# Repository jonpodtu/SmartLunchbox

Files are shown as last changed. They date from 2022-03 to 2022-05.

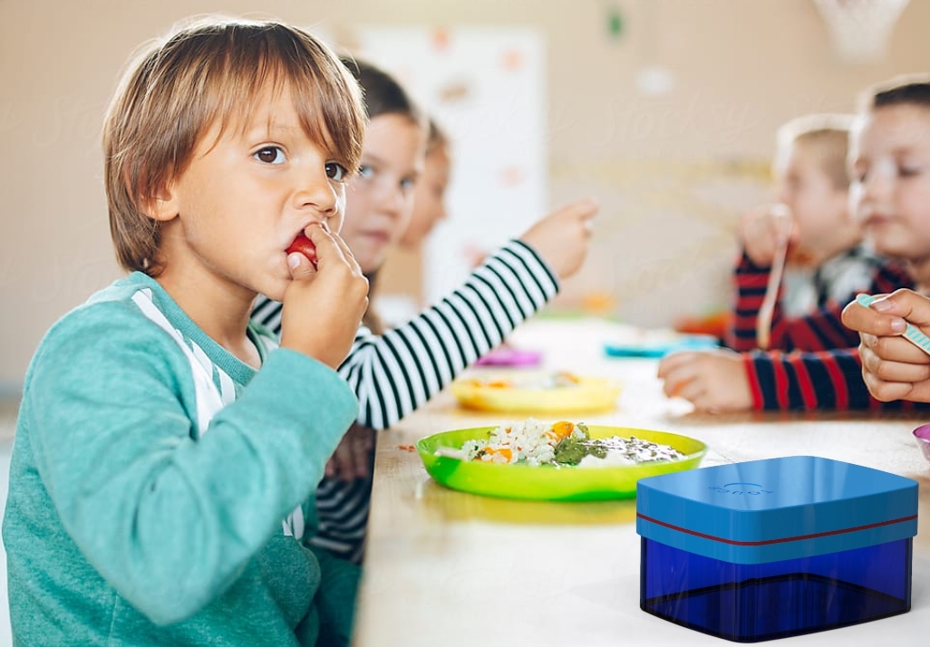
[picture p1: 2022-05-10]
renderings/Front page report.jpg

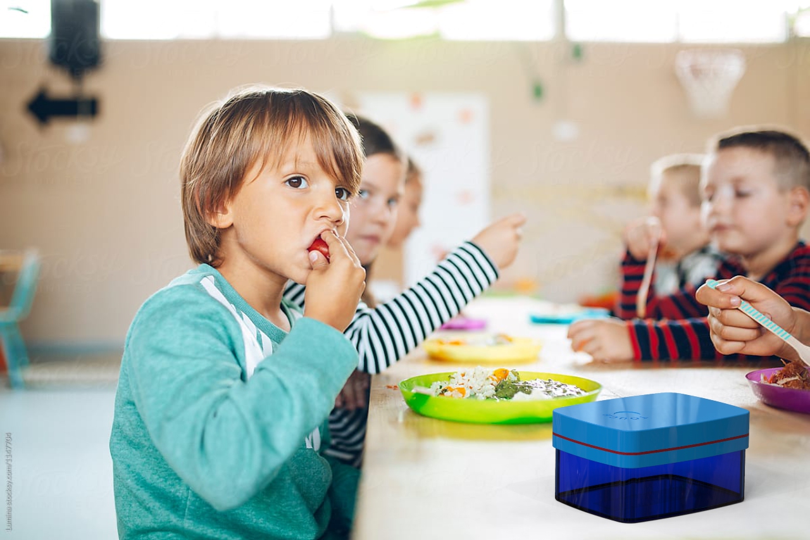
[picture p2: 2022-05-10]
renderings/Front page.jpg

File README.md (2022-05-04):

# SmartLunchbox
Repository for the SmartLunchbox project developed in course 34315

# Note to self
## GPIO Pins
Using the ESP32, we have the following connection for each of the different modules. All module use 5V. 

__MAX7219 LED Dot Matrix Module__
CLK: 2
SCL: 0
DIN: 4

__Photoresistor__
Analog Signal: 27

__DS18B20 Temperature Sensor__
Digital Signal: 26

__TTP223 Touch Sensor Module__
I/O: 15

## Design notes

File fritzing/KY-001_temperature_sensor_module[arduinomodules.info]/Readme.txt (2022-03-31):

//
// ARDUINOMODULES.INFO
// KY-001 Temperature sensor module
//
// https://arduinomodules.info/ky-001-temperature-sensor-module/
//

File includes:
 |
 |- KY-001 Temperature Sensor Module.fzpz	//Fritzing Custom Part
 |
 |- Readme.txt					//This file 

Changelog:
  
  Oct-2020
    -Fix PCB holes.
    -Fix PCB size.
    -Fix copper layers order on PCB.

Disclaimer:

KY-001 Temperature sensor module Fritzing Part is created by arduinomodules.info and published under Creative Commons Attribution-ShareAlike 4.0 International license (https://creativecommons.org/licenses/by-sa/4.0/).
You can use it, share it and/or modify it for any purposes as long as you distribute it under the same license and provide appropriate credit.

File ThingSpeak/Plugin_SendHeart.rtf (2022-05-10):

Title: Send Heart to Child (Plugin)
HTML Code:
<!-- This blog was used to create this functionality https://bennthomsen.wordpress.com/iot/iot-things/ti-cc3200-launchpad/sending-commands-to-device/ -->
<!DOCTYPE html>
<html style="height: 100%;">
<head>
<script type="text/javascript" src="//ajax.googleapis.com/ajax/libs/jquery/1.9.1/jquery.min.js"></script>

<style type="text/css">
body { background-color: white; }
</style>

<script type="text/javascript">
function heartOn(){
$.post('https://api.thingspeak.com/talkbacks/45773/commands.json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');
}
</script>

</head>
<body>
Click here to send a heart to let your kid know, you are thinking of them
</body>
<body>
<button onclick="heartOn()">Send Heart</button>
</body>
</html>
CSS Code
<style type="text/css">
body { background-color: #ddd; }
</style>
JavaScript Code
<script type="text/javascript">
document.write('<div>javascript active</div>');
</script>

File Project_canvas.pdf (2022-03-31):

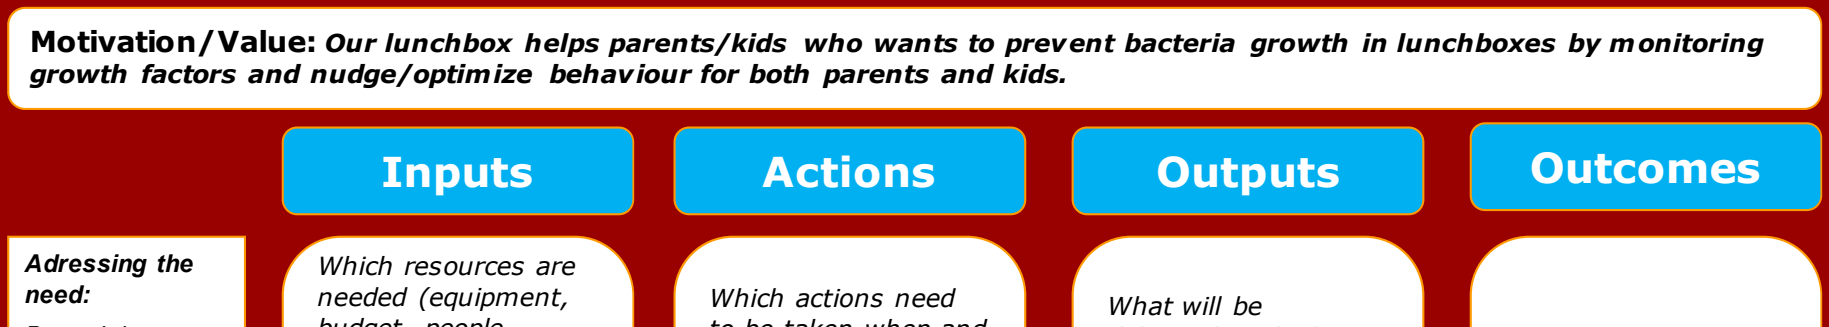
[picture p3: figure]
Adressing the need:; Inputs; Actions; Outputs; Outcomes; Which resources are needed (equipment,; Which actions need; What will be
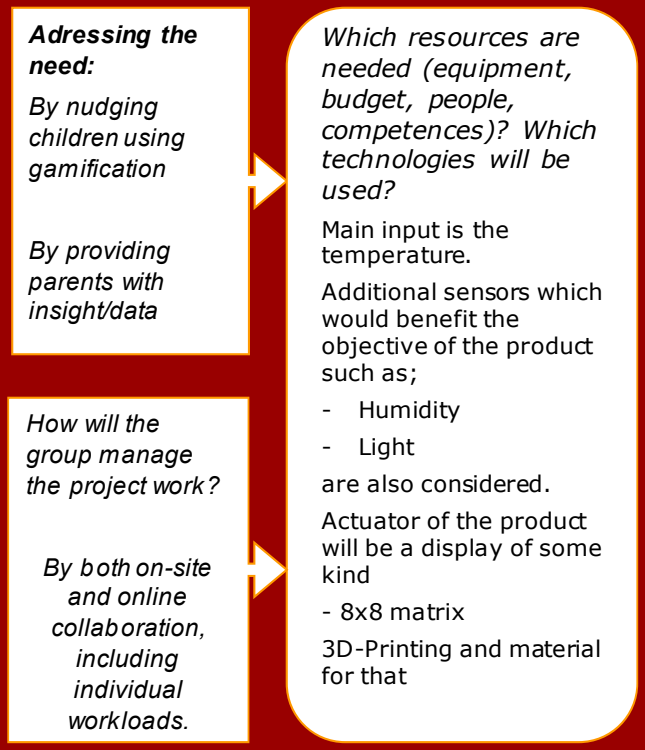
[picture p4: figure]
By nudging children using gamification; By providing parents with insight/data; budget, people, competences)? Which technologies will be used? Main input is the temperature. Additional sensors which would benefit the objective of the product such as; - Humidity - Light are also considered. Actuator of the product will be a display of some kind - 8x8 matrix 3D-Printing and material for that; How will the group manage the project work?; By both on-site and online collaboration, including individual workloads.

srru

IoT Project Planning | Project name: The Smart Lunch Box Group members: Jørgen, Simon, Jonas and Christian

Motivation/Value: Our lunchbox helps parents/kids who wants to prevent bacteria growth in lunchboxes by monitoring growth factors and nudge/optim ize behav iour for both parents and kids.

to be taken when and
by whom?
General structure: Both
online and physical
groupwork depending on
task of the day.
We try to challenge
ourselves by working
with what we are not
typically working with,
and then utilize that we
can aid each other within
different field.
Main responsibilities:
Jørgen: CAD
Simon: Thingspeak and
communication
Christian: C++
Programming
Jonas: Electronics

delivered and when?

### 21. April: 1. Iteration of

complete product.
This will include a 3D
printed lid for the lunchbox which can contain
the electronic
components. It will also
include final electronic
circuit with code that
works. Lastly it will
communicate with
Thingspeak service.

### 28. April: Final product

Polished product where
problems from last
delivery will be fixed.

### 4. May: Handin rapport

and presentation.

The project will help
school children avoid
bacteria corrupted
lunch boxes.

It will help parent
monitor and teach
children good food
safety practice.

If the project can
succesfully nudge
these behaviours, it
is a succes.

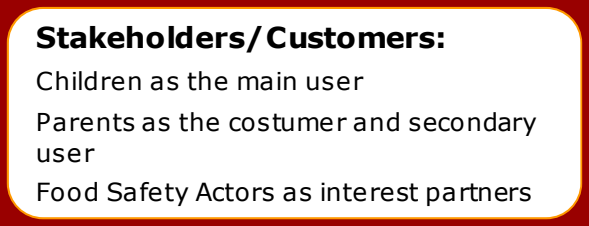
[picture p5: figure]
Stakeholders/Customers:; Children as the main user Parents as the costumer and secondary user Food Safety Actors as interest partners

### Assumptions: Assuming the environment of a brought-to-school lunch and the

possibility of storing this in a fridge.

Risks: What are the risks of the project? We will think about how the product should be designed to make it suitable for the environment. (Washable ie. Water resistant, placement of device etc.)

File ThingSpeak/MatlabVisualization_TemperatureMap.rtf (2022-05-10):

Title: Temperature Zone Map
Matlab Code:
% To create this plot, the following template from Thingspeak was used:
%Template MATLAB code for visualizing data from a channel as a 2D line
% TODO - Replace the [] with channel ID to read data from:
readChannelID = 1671827;
% TODO - Replace the [] with the Field ID to read data from:
fieldID1 = 1;

% Channel Read API Key
% If your channel is private, then enter the read API
% Key between the '' below:
readAPIKey = 'BSZB7OSERJ3O70S9';

%% Read Data %%

[data, time] = thingSpeakRead(readChannelID, 'Field', fieldID1, 'Numdays', 1, 'ReadKey', readAPIKey);

%Using plot first, to set a default window.
plot(time, data);
hold on

%Filling of diff. background zones
x = [0 100 100 0];
y = [5 5 8 8];
tz3 = fill(x,y,'green', 'LineStyle', 'none');
tz3.FaceAlpha = 0.5;
x = [0 100 100 0];
y = [0 0 5 5];
tz1 = fill(x,y,'green', 'LineStyle', 'none');
tz1.FaceAlpha = 0.8;
x = [0 100 100 0];
y = [8 8 40 40];
tz2 = fill(x,y,'red', 'LineStyle', 'none');
tz2.FaceAlpha = 0.5;
x = [0 100 100 0];
y = [40 40 120 120];
tz4 = fill(x,y,'red', 'LineStyle', 'none');
tz4.FaceAlpha = 0.8;

%Setting the window frame
xlim([min(time) max(time)])
ylim([0 max(data)+5])

%%Redraw the graph
plot(time, data, 'color', 'b', 'LineWidth', 1);
legend({'Temperature'})
hold off

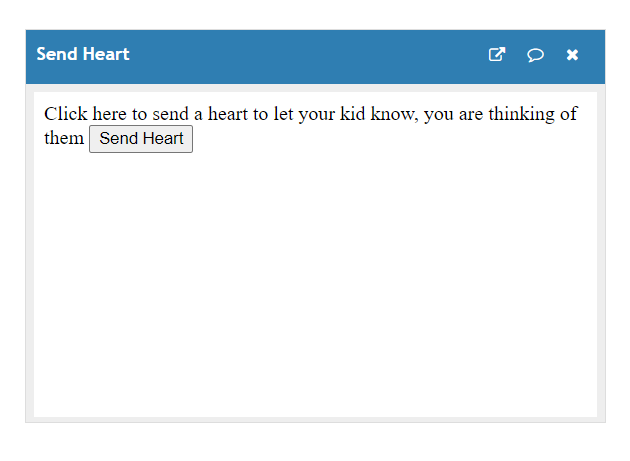
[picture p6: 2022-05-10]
ThingSpeak/HTML Pluging to send Heart.png

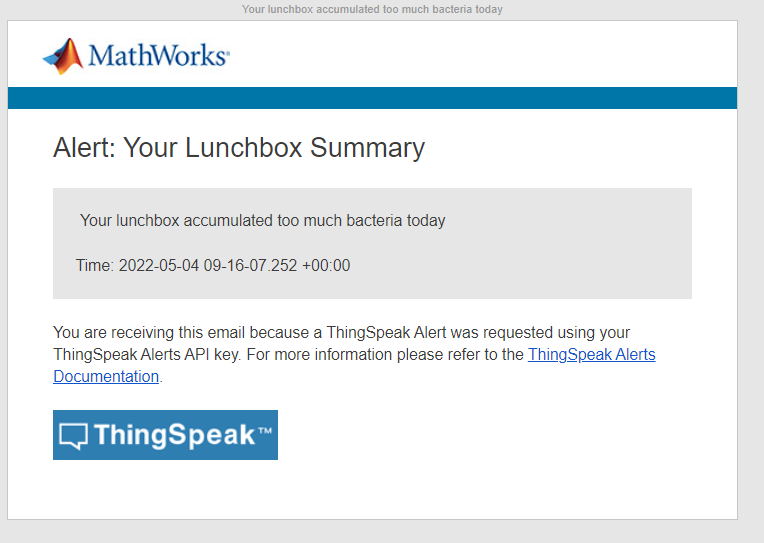
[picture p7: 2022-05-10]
ThingSpeak/Email_from_ThingSpeak.png

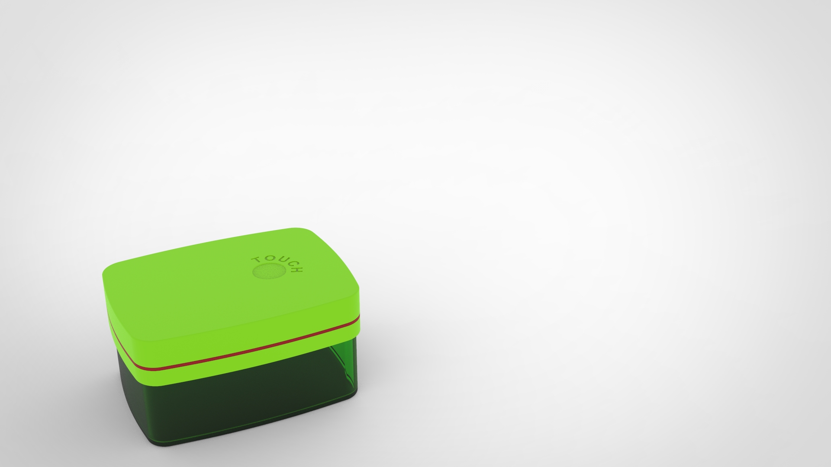
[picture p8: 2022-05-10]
renderings/Foodbox1.jpg

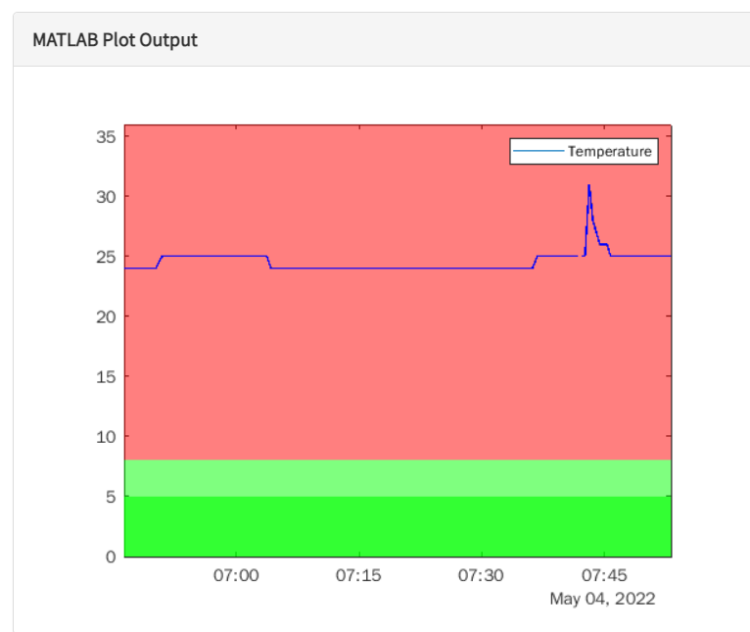
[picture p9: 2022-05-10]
ThingSpeak/temperature_map_UI.png

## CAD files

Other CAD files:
CAD/Lunchbox v1.0 v10.f3d

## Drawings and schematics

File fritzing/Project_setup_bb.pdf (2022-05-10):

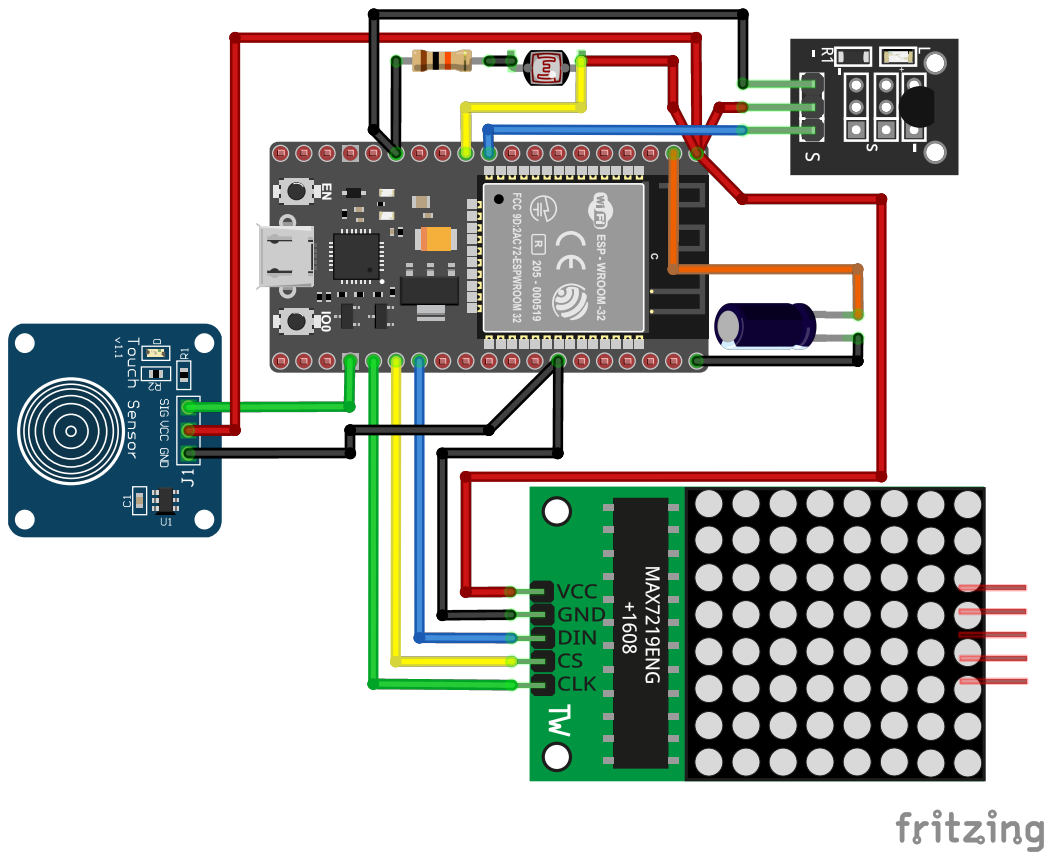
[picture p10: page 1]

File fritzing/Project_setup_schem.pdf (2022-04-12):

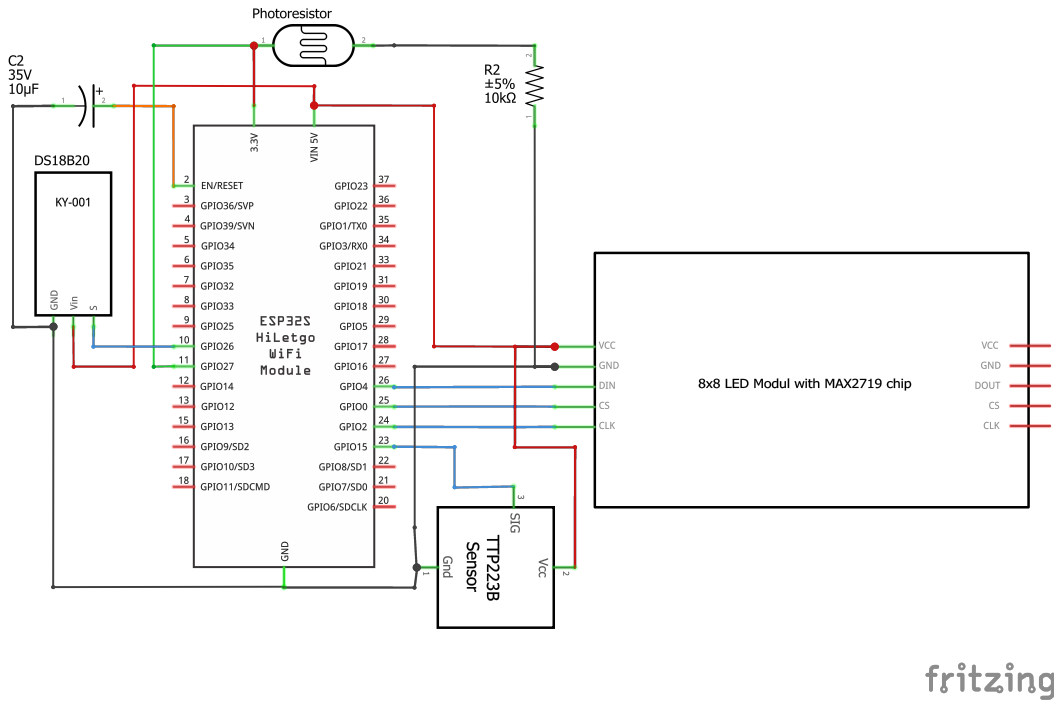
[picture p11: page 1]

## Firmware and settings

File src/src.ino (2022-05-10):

// Import Libraries
#include <WiFi.h>
#include <OneWire.h>
#include <DallasTemperature.h>
#include "LedControl.h"
#include <ThingSpeak.h>

// Setup temperature sensor
#define ONE_WIRE_BUS 26
OneWire ourWire(ONE_WIRE_BUS);
DallasTemperature sensors(&ourWire);

// Assign display:
LedControl lc = LedControl(4,2,0,1); // DIN, CLK, CS

// Assign photoresistor
const int photoPin = 32; // select the input pin for the photoresistor

// Global Variables to use with Millis
unsigned long startMillis;  //some global variables available anywhere in the program
unsigned long currentMillis;
unsigned long measurementMillis = 0;
unsigned long talkbackMillis = 0;
const unsigned long talkback_interval = 5*60*1000; // Take a check for qued messages every (5) minutes etc.- Can be changed for debugging
const unsigned long measurement_interval = 15*60*1000; // Take a measurement every (15) minutes etc.- Can be changed for debugging

// Global variables to use with the sensors:
int temperature;
int sunlight;

// The temperature threshold is the value, where temperatures above speed up bacteria growth
float temp_threshold = 8.0;
int counter_temp = 0;
int counter_threshold = 8;

// Assign the touch sensor 
bool lc_on = true;
int buttonPin = 15;
int buttonState = 0;
unsigned int old_time;

// Time for the heart:
unsigned int heart_time;

// Define all icons:
byte happy[] = {B00111100,B01000010,B10100101,B10000001,B10100101,B10011001,B01000010,B00111100};
byte sad[] = {B00111100,B01000010,B10100101,B10011001,B10011001,B10100101,B01000010,B00111100};
byte heart[] = {B00000000,B01100110,B11111111,B11111111,B01111110,B00111100,B00011000,B00000000};

// Mathworks guide referenced throughout the code: https://se.mathworks.com/help/thingspeak/control-a-light-with-talkback-and-esp32.html

/////////////////////////////////////
/////// Initialize Thingspeak ///////
/////////////////////////////////////
// The below lines 56-63 is taken from the course Thingspeak.ino file:
#define ssid "Christian - iPhone" //Indsæt navnet på jeres netværk her
#define password "04130413" //Indsæt password her

WiFiClient client;

unsigned long channelID = 1671827; //your channel
const char * myWriteAPIKey = "BSZB7OSERJ3O70S9"; // your WRITE API key const char *
const char * server = "api.thingspeak.com";

// Two lines below from mathworks to setup talkback: 
unsigned long myTalkBackID = 45773;
const char * myTalkBackKey = "XMDLP9ZTHSXRY7WL";

void setup() {
  // put your setup code here, to run once:
  Serial.begin(9600);
  delay(10);

  //Wakeup call for The MAX72XX
  lc.shutdown(0,false);
  // Set the brightness to medium value
  lc.setIntensity(0,15);
  display_icon(happy);
  delay(5000);
  // Finally Clear Display
  lc.clearDisplay(0);

  // Define pinmode for toch-sensor
  pinMode(buttonPin, INPUT);

  // Start the millis:
  startMillis = millis();

  // Begin temperature sensor
  sensors.begin(); 

  // Do an initial reading before wifi is connected to confirm that everything works:
  Serial.println("INITIAL READINGS: ");
  temperature = read_temperature();
  sunlight = read_sunlight();
  Serial.print("Temperature: ");
  Serial.println(temperature);
  Serial.print("Sunlight: ");
  Serial.println(sunlight);

  // Connecting to WiFi network. Below lines 102 to 118 is taken from the Thingspeak.ino file from the course:
  Serial.println();
  Serial.print("Connecting to ");
  Serial.println(ssid);

  WiFi.mode(WIFI_STA); // From the mathworks guide

  WiFi.begin(ssid, password);
  
  while (WiFi.status() != WL_CONNECTED) {
    delay(500);
    Serial.print(".");
  }
  Serial.println("");
  Serial.println("WiFi connected");

}

void loop() {
  // put your main code here, to run repeatedly:
  currentMillis = millis();

  // Check talkback:
  // Below from mathworks guide:
  String message = "None";
  
  // Clear display of heart if it has been shown for more than seven seconds.
  if ((currentMillis > heart_time) && !lc_on) {
      lc.clearDisplay(0);
  }
  
  // Check if five minutes have passed since last talkback check:
  if (currentMillis >= (talkback_interval + talkbackMillis)){
    Serial.println("Checking talkback");
    talkbackMillis = millis();
    message = check_talckback();
   
  }
  
  if (message.indexOf("HEART_ON") > 0) {
    // As this does not depend on counter we manually set intensity of sunlight reading:
    sunlight = read_sunlight();
    int intensity = map(sunlight, 500, 4095, 3, 15);
    lc.setIntensity(0,intensity);
    Serial.println("SHOWING HEART");
    display_icon(heart);
    heart_time = millis() + 7000;
  }

  // Check if fifteen minutes have passed since last measurement:
  if (currentMillis >= (measurement_interval + measurementMillis)){
      // Measure:
      temperature = read_temperature();
      Serial.print("Temperature: ");
      Serial.println(temperature);
      sunlight = read_sunlight();


      // The below code lines 160-168 is heavily inspired by the Thingspeak.ino file given in the course:
      ThingSpeak.begin(client);
      if (client.connect(server, 80)) {
        Serial.print("Sending to thingspeak ...");
        ThingSpeak.setField(1,temperature);
        ThingSpeak.writeFields(channelID, myWriteAPIKey);
        Serial.print("Sent!");
      
      }
      client.stop();
      
      // After measurement is taken, determine whether or not the display should change:
      if (increment(temperature, temp_threshold)){
        counter_temp += 1;
        Serial.print("Counter Temp: ");
        Serial.println(counter_temp);
      }
  measurementMillis = millis();
  }
  
  // Reset display if symbol has been shown for seven seconds:
  if ((lc_on) && (currentMillis > old_time))
  {
    Serial.println("Resetting display");
    lc.clearDisplay(0);
    lc_on = false;
  }
  else if (!lc_on)
  {
    buttonState = digitalRead(buttonPin); //If button is pushed, and display is off, activate display.
    if(buttonState == HIGH)
    {
      display(counter_temp, sunlight);
      lc_on = true;
      old_time = millis() + 7000;
    }
  }

}

//////////////////////////////
////// Define functions //////
//////////////////////////////

// Temperature
int read_temperature(){
  sensors.requestTemperatures(); 
  return sensors.getTempCByIndex(0);
}

// Sunlight
int read_sunlight(){
  return analogRead(photoPin);
}

// Activate display
void display(int counter, int sunlight_reading){
  int intensity = map(sunlight_reading, 500, 4095, 3, 15);
  Serial.print("Intensity");
  Serial.println(intensity);
  lc.setIntensity(0,intensity);
  if (counter < 8){
    display_icon(happy);

  } else {
    display_icon(sad);
  }
}

// Display icon
void display_icon(byte icon[]){
  for(int i = 0; i < 8; i++){
    lc.setRow(0,i,icon[i]);
  }
}

// Counter incrementation
bool increment(int measurement, float measurement_threshold){
  if (measurement >= measurement_threshold) {
    return true;
  }
  else {return false;}
}


// Talkback setup function taken form mathworks, edited to be compatible with our code and thingspeak signal:
String check_talckback(){
  // Create the TalkBack URI
  String tbURI = String("/talkbacks/") + String(myTalkBackID) + String("/commands/execute");
  
  // Create the message body for the POST out of the values
  String postMessage =  String("api_key=") + String(myTalkBackKey);                      
                       
   // Make a string for any commands that might be in the queue
  String newCommand = String();

  // Make the POST to ThingSpeak
  int x = httpPOST(tbURI, postMessage, newCommand);
  client.stop();
  
  // Check the result
  if(x == 200){
    Serial.println("checking queue..."); 
    // check for a command returned from TalkBack
    if(newCommand.length() != 0){

      Serial.print("  Latest command from queue: ");
      Serial.println(newCommand);
      return newCommand;
    }
    else{
      Serial.println("  Nothing new.");
      return "None";
    }
    
  }
  else{
    Serial.println("Problem checking queue. HTTP error code " + String(x));
    return "None";
  }
}

// General function to POST to ThingSpeak taken from mathworks:
int httpPOST(String uri, String postMessage, String &response){

  bool connectSuccess = false;
  connectSuccess = client.connect("api.thingspeak.com",80);

  if(!connectSuccess){
      return -301;   
  }
  
  postMessage += "&headers=false";
  
  String Headers =  String("POST ") + uri + String(" HTTP/1.1\r\n") +
                    String("Host: api.thingspeak.com\r\n") +
                    String("Content-Type: application/x-www-form-urlencoded\r\n") +
                    String("Connection: close\r\n") +
                    String("Content-Length: ") + String(postMessage.length()) +
                    String("\r\n\r\n");

  client.print(Headers);
  client.print(postMessage);

  long startWaitForResponseAt = millis();
  while(client.available() == 0 && millis() - startWaitForResponseAt < 5000){
      delay(100);
  }

  if(client.available() == 0){       
    return -304; // Didn't get server response in time
  }

  if(!client.find(const_cast<char *>("HTTP/1.1"))){
      return -303; // Couldn't parse response (didn't find HTTP/1.1)
  }
  
  int status = client.parseInt();
  if(status != 200){
    return status;
  }

  if(!client.find(const_cast<char *>("\n\r\n"))){
    return -303;
  }

  String tempString = String(client.readString());
  response = tempString;

  Serial.println("The httpPost has run");
  return status;
}

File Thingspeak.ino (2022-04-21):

// Including the ESP8266 WiFi library
#include <ESP8266WiFi.h>
#include <DHT.h>
#include <ThingSpeak.h>

// Uncomment one of the lines below for whatever DHT sensor type you're using!
#define DHTTYPE DHT11   // DHT 11


// Replace with your network details
const char* ssid = "IoTFotonik";
const char* password = "Cyberteknologi";





WiFiClient client;

const int DHTPin = D3;
// Initialize DHT sensor.
DHT dht(DHTPin, DHTTYPE);

// Temporary variables
static char celsiusTemp[7];
static char fahrenheitTemp[7];
static char humidityTemp[7];


unsigned long channelID = 900XXX; //your channel
const char * myWriteAPIKey = "M28GRUEIUPXSXXX"; // your WRITE API key
const char* server = "api.thingspeak.com";

const int postingInterval = 20 * 1000; // post data every 20 seconds

// only runs once on boot
void setup() {
  // Initializing serial port for debugging purposes
  Serial.begin(115200);
  delay(10);

  dht.begin();
  
  // Connecting to WiFi network
  Serial.println();
  Serial.print("Connecting to ");
  Serial.println(ssid);
  
  WiFi.begin(ssid, password);
  
  while (WiFi.status() != WL_CONNECTED) {
    delay(500);
    Serial.print(".");
  }
  Serial.println("");
  Serial.println("WiFi connected");
  
}

// runs over and over again
void loop() {
  ThingSpeak.begin(client);
  if (client.connect(server, 80)) {
    
    // Measure Signal Strength (RSSI) of Wi-Fi connection
    long rssi = WiFi.RSSI();

    Serial.print("RSSI: ");
    Serial.println(rssi); 


    ThingSpeak.setField(4,rssi);

// **** This part reads only sensors and calculates
            // Sensor readings may also be up to 2 seconds 'old' (its a very slow sensor)
            float h = dht.readHumidity();
            // Read temperature as Celsius (the default)
            float t = dht.readTemperature();
            // Read temperature as Fahrenheit (isFahrenheit = true)
            float f = dht.readTemperature(true);
            // Check if any reads failed and exit early (to try again).
            if (isnan(h) || isnan(t) || isnan(f)) {
              Serial.println("Failed to read from DHT sensor!");
              strcpy(celsiusTemp,"Failed");
              strcpy(fahrenheitTemp, "Failed");
              strcpy(humidityTemp, "Failed");         
            }
            else{
              // Computes temperature values in Celsius + Fahrenheit and Humidity
              float hic = dht.computeHeatIndex(t, h, false);       
              dtostrf(hic, 6, 2, celsiusTemp);             
              float hif = dht.computeHeatIndex(f, h);
              dtostrf(hif, 6, 2, fahrenheitTemp);         
              dtostrf(h, 6, 2, humidityTemp);

              // You can delete the following Serial.print's, it's just for debugging purposes
              Serial.print("Humidity: ");
              Serial.print(h);
              Serial.print(" %\t Temperature: ");
              Serial.print(t);
              Serial.print(" *C ");
              Serial.print(f);
              Serial.print(" *F\t Heat index: ");
              Serial.print(hic);
              Serial.print(" *C ");
              Serial.print(hif);
              Serial.print(" *F");
              Serial.print("Humidity: ");
              Serial.print(h);
              Serial.print(" %\t Temperature: ");
              Serial.print(t);
              Serial.print(" *C ");
              Serial.print(f);
              Serial.print(" *F\t Heat index: ");
              Serial.print(hic);
              Serial.print(" *C ");
              Serial.print(hif);
              Serial.println(" *F");
        //end of sensor readings
              ThingSpeak.setField(1,t);
              ThingSpeak.setField(2,f);
              ThingSpeak.setField(3,h);
            }
            
      ThingSpeak.writeFields(channelID, myWriteAPIKey);
  }
    client.stop();

  // wait and then post again
  delay(postingInterval);
}

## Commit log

2022-03-31 updated fritzin
    [Project_setup.fzz]
2022-04-07 more fritzing and datasheets
    [Project_setup.fzz]
2022-04-07 Comitted first build, still need to work with the touch sensor
2022-04-12 Finished fritzing and edited code
    [Project_setup.fzz]
2022-04-21 updated fritzing (3.3V)
    [Project_setup-LAPTOP-RORHF012.fzz, Project_setup.fzz]
